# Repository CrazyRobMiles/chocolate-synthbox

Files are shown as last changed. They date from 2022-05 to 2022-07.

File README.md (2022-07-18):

# chocolate-synthbox
Raspberry Pi and PICO powered musical instrument running Pure Data

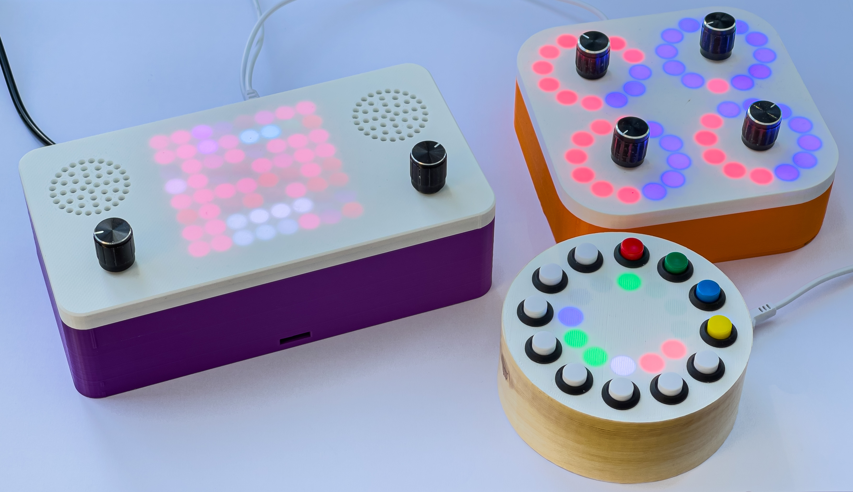
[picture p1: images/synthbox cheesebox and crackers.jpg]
Chocolate Synthbox, midi CheeseBox and crackers controller

# Video
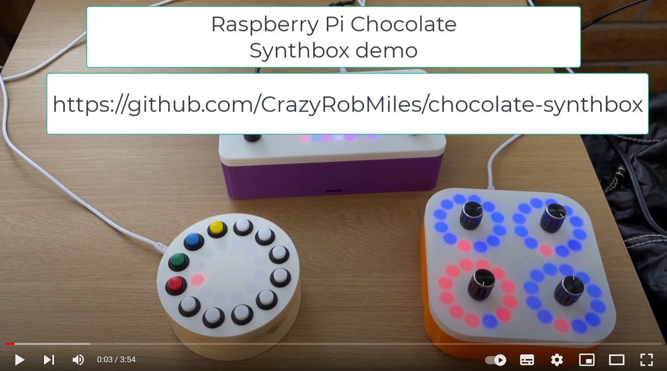
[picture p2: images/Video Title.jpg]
YouTube Screenshot (https://youtu.be/IFDrWa9PeCk)


To find out more about the device click on the image above to see a short video.
# Parts list
* Raspberry Pi. The software works with any Pi from the Zero upwards, but for more interesting sounds a Pi 4 is best
* Pi soundcard and amplifier. I used the Waveshare WM8960 but you can also use the Adafruit I2S 3W stereo speaker bonnet
* Pixel panel. The prototype uses an Adafruit NeoPixel NeoMatrix 8x8 - 64 RGB LED Pixel Matrix. This board is 71mm x 71mm. You can get WS2812 8x8 pixel matrices which are smaller (65mm square). There are printable case designs for each size. 
* Two rotary encoders (search for KY-040 encoder)
* A small speaker (You can get a very nice one from Pimoroni: https://shop.pimoroni.com/products/mini-speaker-4-3w)
* You can get the connectors you need to power the Pi and the PICO buy buying a USB-C Power Splitter for Raspberry Pi Touchscreen Display
* A Female 5.5mm x 2.1mm power socket 
* A power supply capable of supplying 5 volts at least 4 amps with a 5.5mm x 2.1mm plug.
* Connecting wire (search for "30 AWG wire wrap") which needs a wire wrap tool (search for "wire wrap tool").
* A box. There are a 3D printable designs available.
* Screws. You'll need some screws sized M2 4mm in length to fix things to the case (search for "laptop screws")
# Circuit Diagram
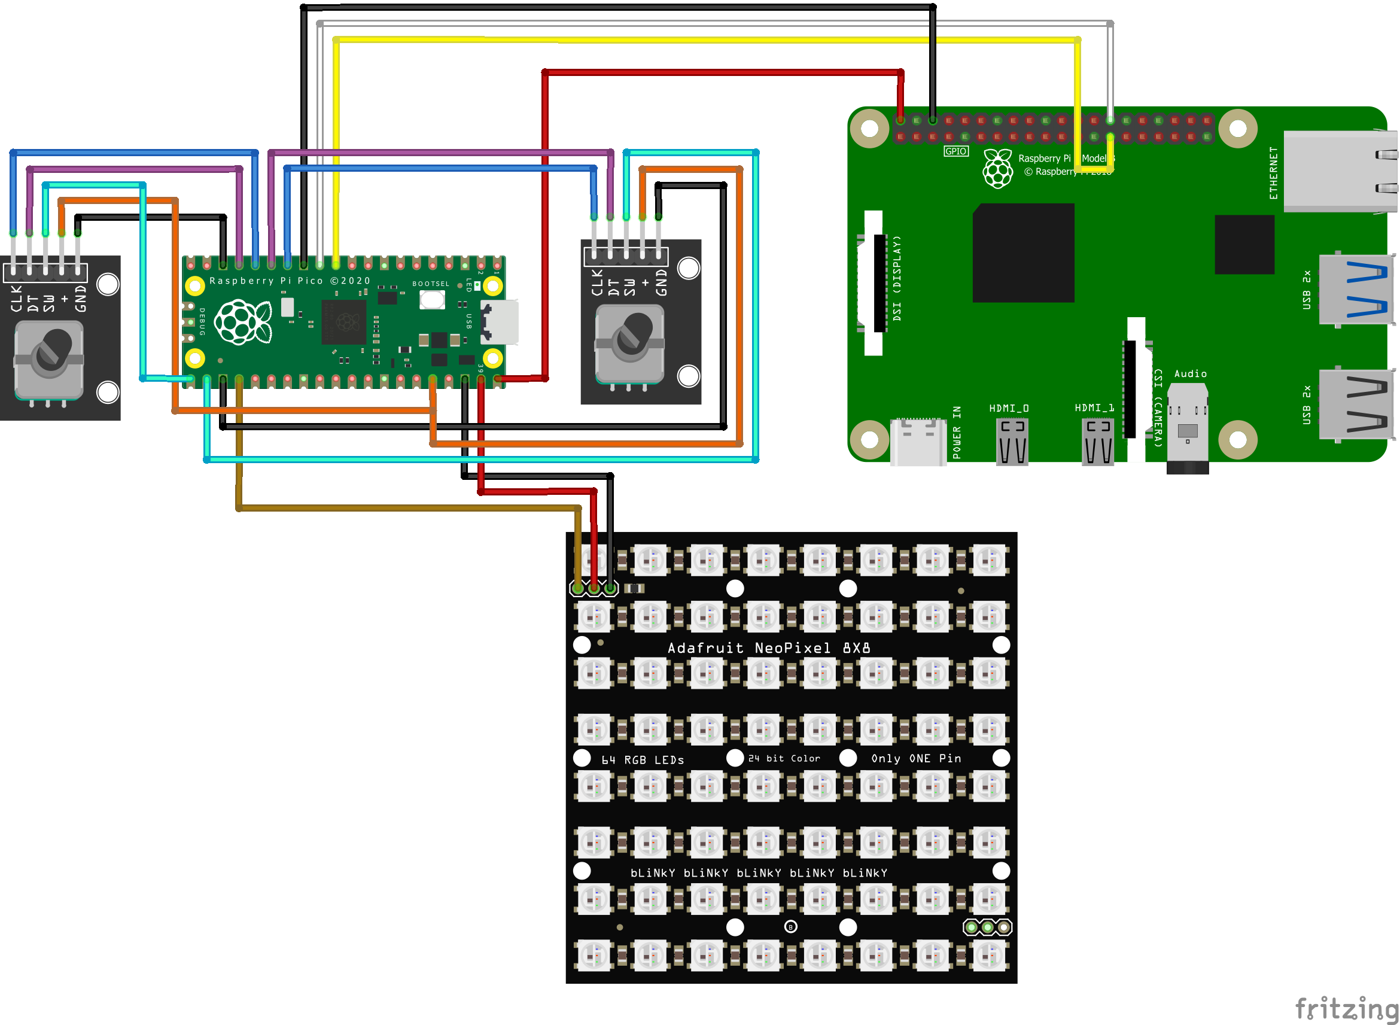
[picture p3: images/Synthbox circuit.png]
device circuit diagram

# Set up the Pico
Copy the program and libraries onto the Pico device. The Pico program is in the file code.py in the root of this repository. This is so you can use the Pymakr plugin to download and run the program from this repository. You will need to copy the contents of the lib folder onto your Pico as this contains Circuit Python libraries. 
# Set up the Raspberry Pi
## Get the operating system
Install the latest version of the Raspberry Pi operating system. Don't install the headless version because you will  need to use the desktop to configure Pure Data.
## Install the sound hardware 
Plug your sound hat onto your Raspberry Pi and install the driver software for it. If you are using the WaveShare sound hat you can use the installer [here](https://www.waveshare.com/wiki/WM8960_Audio_HAT#Install_Driver).

## Enable serial port 2
Note that serial port 2 in this configuration only works on a Raspberry Pi 4. 
Enable the serial port 2. This is the port that links the Pi to the Pico. We are going to use the second serial port which is exposed as /dev/ttyAMA1. It uses the GPIO0 (TX) and GPIO1 (RX) pins on the Raspberry Pi. These are on pins 27 and 28 respectively on the GPIO connector. We enable this port by adding the following line at the end of the file /boot/config.txt:
```
sudo nano /boot/config.txt
```
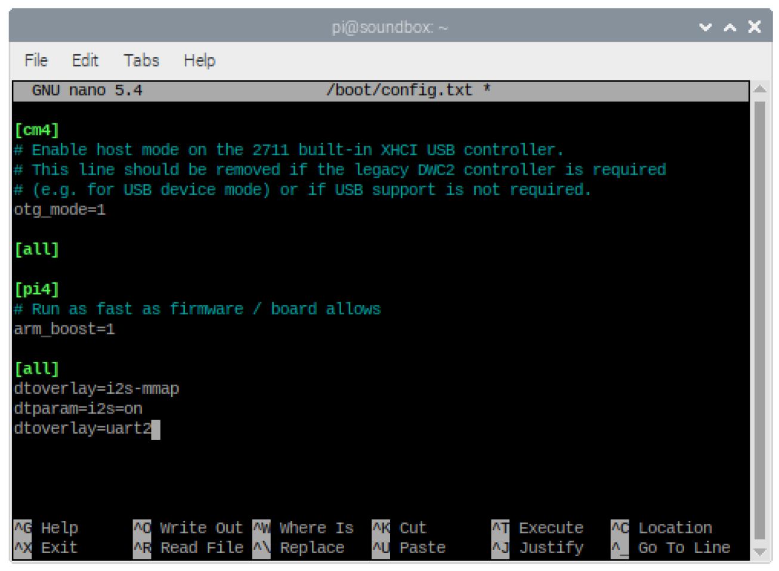
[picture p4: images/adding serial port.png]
nano editing config.txt


```
dtoverlay=uart2
```
Add the line as show above, write and save the file. If you want to use a different serial port you will have to modify the SerialComms.pd patch to change the name of the serial device it uses. 
## Install Pure Data and the Pure Data comport
Open up a terminal window and type:
```
sudo apt-get install puredata
sudo apt install pd-comport
```
This will install Pure Data and the comport object used by Pure Data patches to communicate over the serial port. 
## Copy the Pure Data patches to the Pi
You can use a usb drive or a remote desktop connection to copy these onto the your Pi. Copy the  Synthbox folder in the pd-code folder onto the desktop of your Pi. You must put the folder here, otherwise it won't be picked up automatically when the Pi starts. 
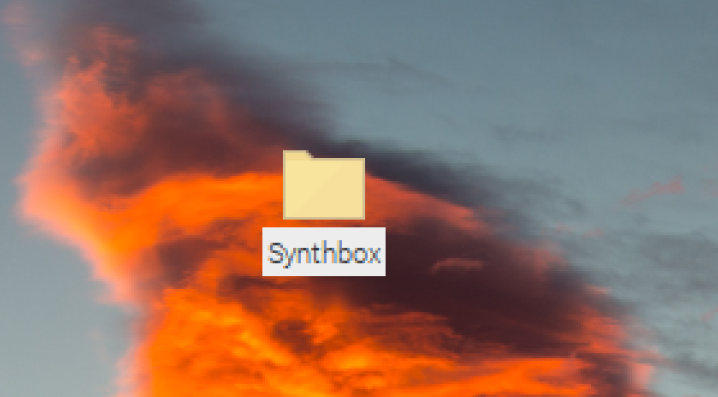
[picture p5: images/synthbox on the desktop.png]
Synthbox on the desktop

## Make Pure Data start on bootup
We can make Pure Data to start each time the Raspberry Pi boots by adding a line to the /etc/xdg/lxsession/LXDE-pi/autostart file. Open the file as follows:
```
sudo nano /etc/xdg/lxsession/LXDE-pi/autostart
```
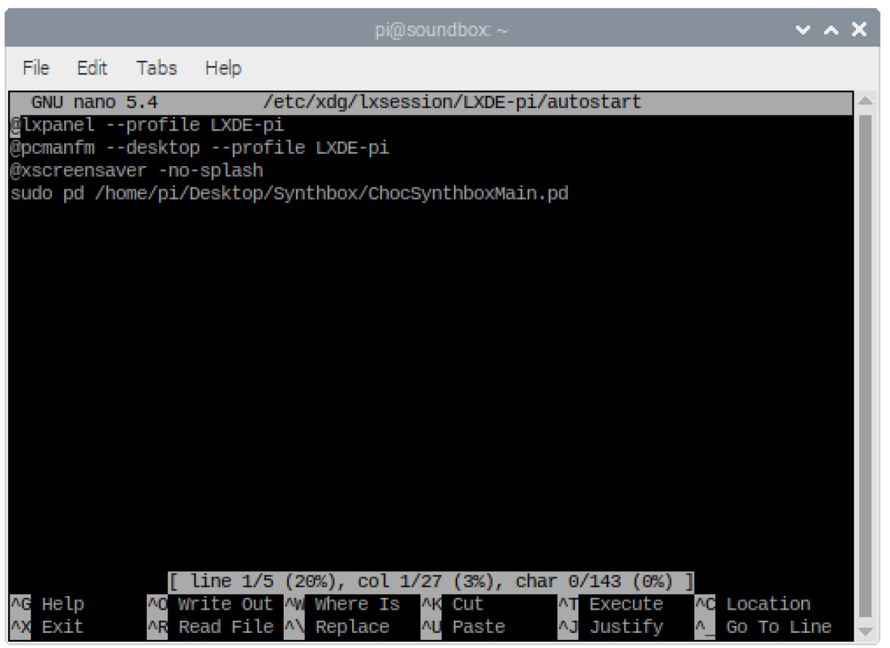
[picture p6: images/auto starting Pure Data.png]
nano editing autostart


Add the line:
```
sudo pd /home/pi/Desktop/Synthbox/ChocSynthboxMain.pd
```
Save the file and close it. Now each time your Pi starts it will run PureData.
## Connect Pure Data to the audio output
Next you need to tell Pure Data to use the audio output device we have installed.
Open up a desktop connection to the Pi, open Pure Data if it is not running and then select File>Preferences>Audio 
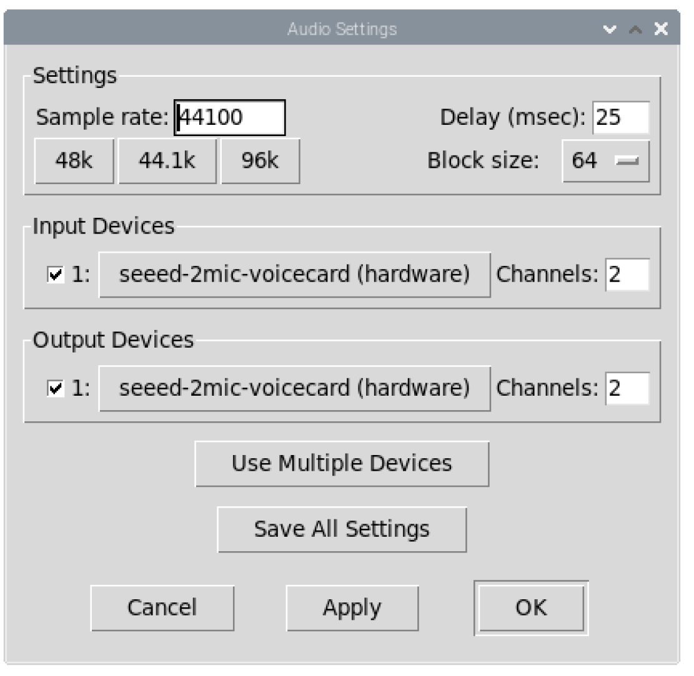
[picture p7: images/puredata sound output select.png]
Selecting Pure Data sound output

Click the input and output devices buttons and select the seeed devices as shown above. 
Then click Save All Settings and OK to save the settings and close the dialog.
## Connect Pure Data to your MIDI devices
Make sure that you have plugged your MIDI devices in before you start Pure Data running. It seems to only check for devices on startup. Open File>Preferences>Midi and select the option to use multiple devices. 
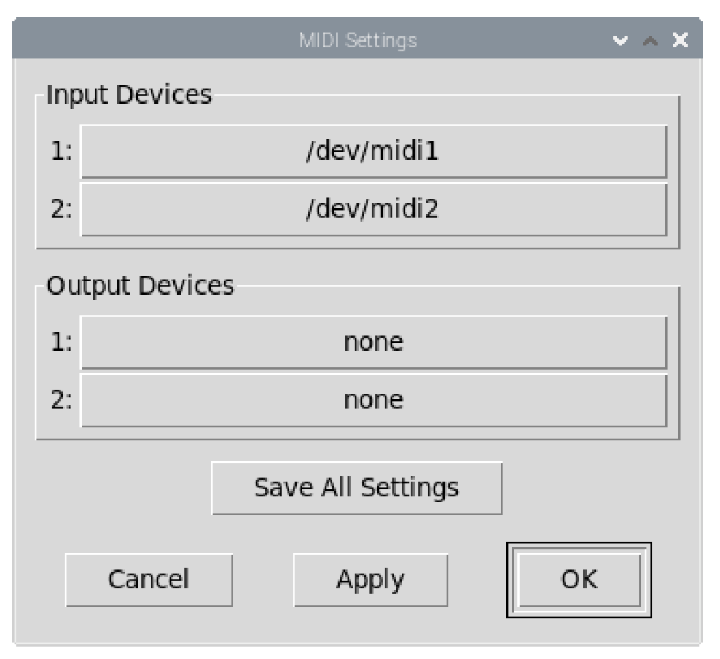
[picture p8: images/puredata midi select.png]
Selecting Pure Data sound output

Then select the MIDI input devices and click Save All Settings and then OK to close the dialog. 
## Run the patch
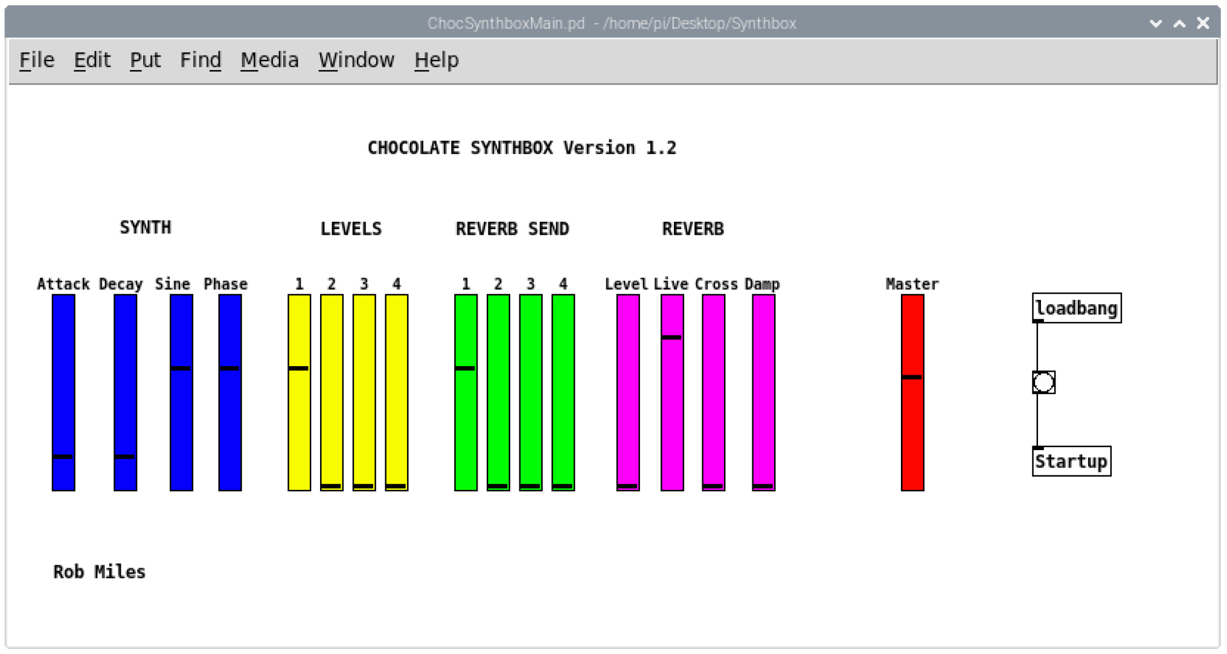
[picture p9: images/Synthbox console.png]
Pure Data console

When the patch is running the above is displayed on the Pi screen. You can use the sliders to adjust the values that are also controlled by the Pico Crackers controller. 

This is a work in progress. But it is fun to play with. 

I hope you have fun with it.

Rob Miles

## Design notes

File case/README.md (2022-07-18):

# Case

There are versions of the case for two sizes of led matrix. 

The case is created by a Python program that can be used to generate cases containing a large number of different elements. The program is called **BoxMacro.FCMacro** and runs inside the FreeCAD design tool which you can download from [here](https://www.freecadweb.org/downloads.php).

Each element in an enclosure is represented by one or more classes which are then automatically placed inside the base or the lid of the case. It is a bit of a pain to work with, I call it "3,000 lines of technical debt" but it does the job.

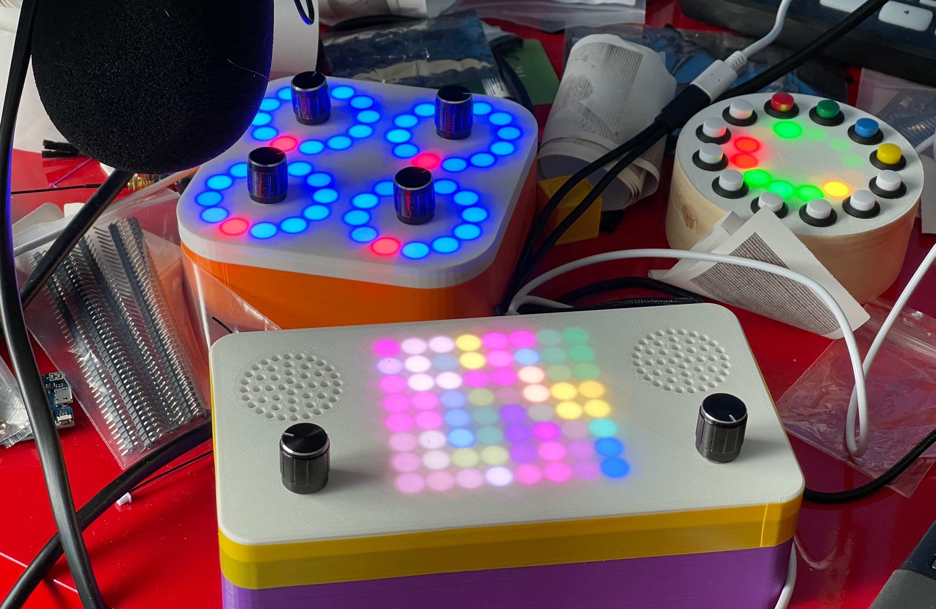
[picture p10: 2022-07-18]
images/soundbox controller and cheesebox.jpg

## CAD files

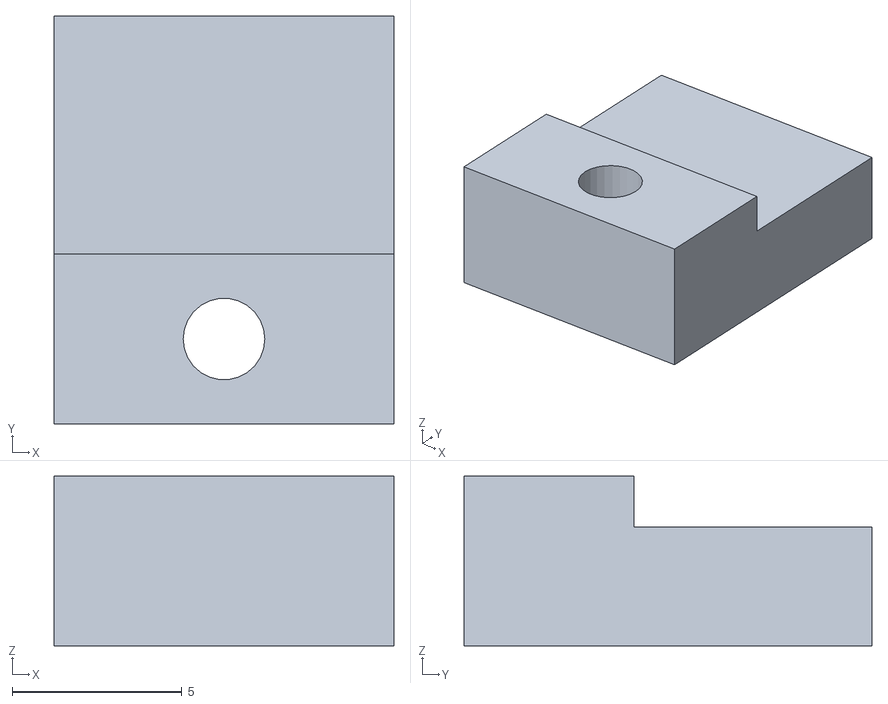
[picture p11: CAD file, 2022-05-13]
case/led panel clamps/clamp.stl
10.0 x 12.0 x 5.00

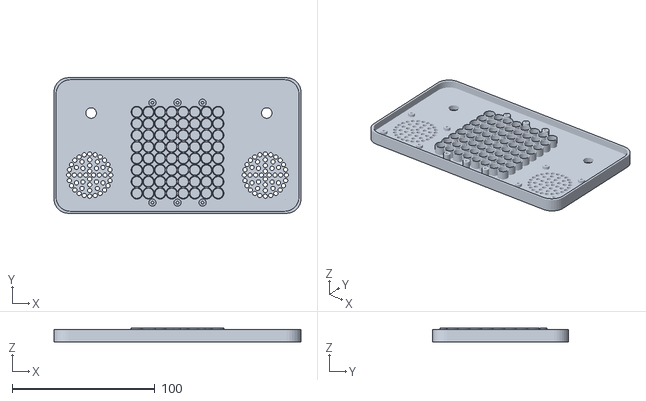
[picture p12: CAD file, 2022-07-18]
case/Synthbox 65mm matrix/top.stl
173.0 x 95.0 x 10.0

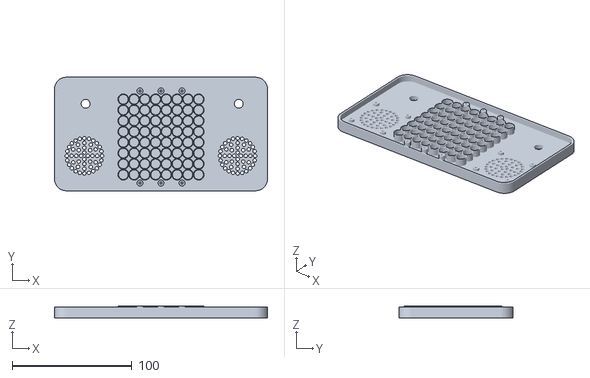
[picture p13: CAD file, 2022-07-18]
case/Synthbox 71mm matrix/top.stl
178.0 x 95.0 x 10.0

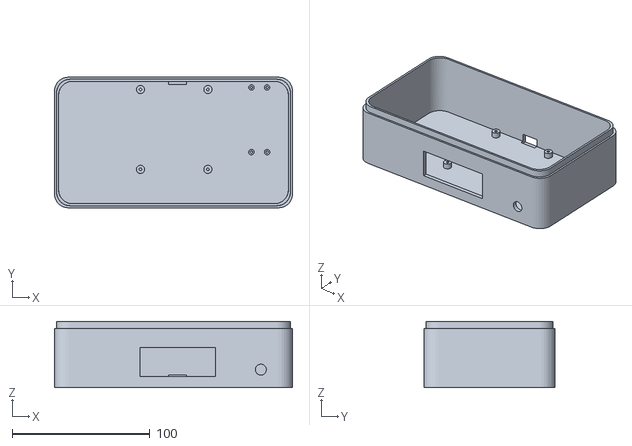
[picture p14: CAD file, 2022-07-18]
case/Synthbox 65mm matrix/bottom.stl
173.0 x 95.0 x 48.0

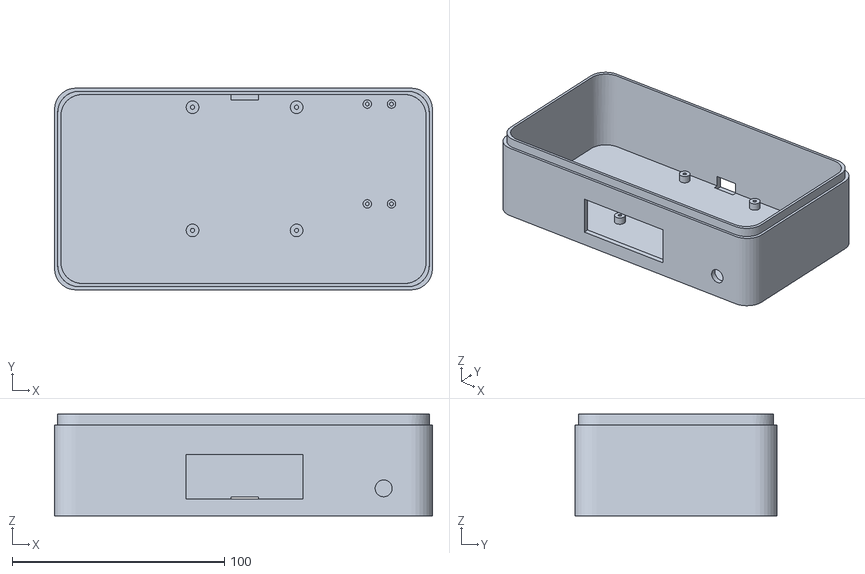
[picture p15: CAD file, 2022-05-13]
case/Synthbox 71mm matrix/bottom.stl
178.0 x 95.0 x 48.0

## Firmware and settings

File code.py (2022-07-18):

import board
import time
import busio
import gc
import board
import neopixel
import rotaryio
from digitalio import DigitalInOut, Direction, Pull
from adafruit_debouncer import Debouncer

class Types:
    NUMBER_INPUT = "no"
    TEXT_INPUT = "text"

class Col:
    
    RED = (255, 0, 0)
    YELLOW = (255, 150, 0)
    GREEN = (0, 255, 0)
    CYAN = (0, 255, 255)
    BLUE = (0, 0, 255)
    MAGENTA = (255, 0, 255)
    WHITE = (255, 255, 255)
    BLACK = (0, 0, 0)
    GREY = (10, 10, 10)
    VIOLET = (127,0,155)
    INDIGO = (75,0,130)
    ORANGE = (255,165,0)
       
    values=(RED, GREEN, BLUE, YELLOW, MAGENTA, CYAN, GREY, WHITE)
     
   
    @staticmethod
    def dim(col):
        return (col[0]/40, col[1]/40, col[2]/40)

class ControllerConfig():
    
    def __init__(self, name, min_val=0, max_val=127,turns=1.0,init_value=0,
                 controller_value = 0, background_col = Col.BLUE,
                 val_col = Col.RED):
        self.name = name
        self.min_val = min_val
        self.max_val = max_val
        self.turns = turns
        self.encoder_value = 0
        self.init_value = init_value
        self.controller_value = init_value
        self.val_col = val_col
        self.background_col = background_col
 
class SerialControllerConfig(ControllerConfig):
    
    def __init__(self, name, min_val=0, max_val=127,turns=1.5,init_value=0,
                 controller_value = 0, background_col = Col.BLUE,
                 val_col = Col.RED, serial_port = None, serial_channel=1,pixel_start=0,no_of_pixels=8, stride=-8):
        super(SerialControllerConfig,self).__init__(
            name, min_val, max_val,turns,init_value,
                 controller_value, background_col,
                 val_col)
        self.serial_port = serial_port
        self.serial_channel = serial_channel
        self.pixel_start = pixel_start
        self.no_of_pixels = no_of_pixels
        self.stride = stride

class Controller():
    def __init__(self, client, name, encoder_pin1, encoder_pin2, pulses_rev,
                 button_pin, forward, configs, cursor_col = Col.WHITE
                 ):
        self.name = name
        self.client =  client
        self.screen_manager = client.screen_manager
        self.encoder= rotaryio.IncrementalEncoder(encoder_pin1, encoder_pin2)
        self.pulses_rev = pulses_rev
        self.last_encoder_position = 0
        tmp_pin = DigitalInOut(button_pin)
        tmp_pin.pull = Pull.UP
        self.button_debounce = Debouncer(tmp_pin,interval=0.01)
        self.activate_display()
        self.forward = forward
        self.first_run = True
        self.cursor_col = cursor_col
        self.configs = configs
        self.active_config_no = 0
        self.active_config = configs[0]
    
    def activate_display(self):
        self.encoder_display_time_end = time.monotonic() + 2

    def display_active(self):
        if time.monotonic() < self.encoder_display_time_end :
            return True
        else:
            return False

    def set_range(self,min_val,max_val,turns,pulses_rev):
        self.min = min_val
        self.max = max_val
        self.turns = turns
        
    def set_pixel_col(self,pixel_number,new_col):
        if self.screen_manager.pixels[pixel_number] != new_col:
            self.screen_manager.pixels[pixel_number] = new_col
            self.screen_manager.controls_active = True
        
    def draw_cursor(self):
        for config in self.configs:
            pixels = config.no_of_pixels
            stride = config.stride
            pulse_limit = int(self.pulses_rev * config.turns)-1
            turn_amount = config.encoder_value / pulse_limit
            cursor = int((pixels-1)*turn_amount)
            pos=0
            pix = config.pixel_start
            while pos < pixels:
                if pos<=cursor:
                    if pos == cursor:
                        if config == self.active_config:
                            self.set_pixel_col(pix, self.cursor_col)
                        else:
                            self.set_pixel_col(pix, config.val_col)
                    else:
                        self.set_pixel_col(pix, config.val_col)
                else:
                    self.set_pixel_col(pix, config.background_col)
                pos = pos + 1
                pix = pix + stride
            
    def update_encoder(self):
        new_encoder_position = self.encoder.position
        encoder_change = self.last_encoder_position - new_encoder_position
        
        if encoder_change != 0 or self.first_run:
            self.activate_display()
            if self.forward:
                new_pos = self.active_config.encoder_value - encoder_change
            else:
                new_pos = self.active_config.encoder_value + encoder_change
                
            if new_pos<0:
                new_pos=0
                
            pulse_limit = int(self.pulses_rev * self.active_config.turns)-1
            
            if new_pos>=pulse_limit:
                new_pos=pulse_limit
                 
            if self.active_config.encoder_value != new_pos or self.first_run:
                self.first_run = False
                self.active_config.encoder_value = new_pos
                turn_amount = new_pos / pulse_limit
                val_range = self.active_config.max_val - self.active_config.min_val
                scaled_change = turn_amount * val_range
                self.active_config.controller_value=scaled_change
                self.encoder_changed()
       
        self.last_encoder_position = new_encoder_position
        
    def update(self):
        self.button_debounce.update()
        if self.button_debounce.fell:
            self.activate_display()
            self.button_down()
        if self.button_debounce.rose:
            self.button_up()
        self.update_encoder()

    def draw(self):
        if self.display_active():
            self.draw_cursor()
            return True
        else:
            return False

    def reset(self):
        self.count=0
        
    def step_controller(self):
        self.active_config_no = (self.active_config_no + 1) % len(self.configs)
        self.active_config = self.configs[self.active_config_no]
        self.draw_cursor()
    
    def button_down(self):
        self.step_controller()
        
    def button_up(self):
        pass


class SerialController(Controller):
    
    def __init__(self, client, name, encoder_pin1, encoder_pin2, pulses_rev,
                 button_pin, forward, configs):
        super(SerialController,self).__init__(client = client, name = name,
                 encoder_pin1 = encoder_pin1, encoder_pin2 = encoder_pin2,
                 pulses_rev = pulses_rev, button_pin = button_pin,
                 forward = forward,
                 configs=configs)
    
    def encoder_changed(self):
        print("Controller changed: ",self.active_config.controller_value,self.active_config.serial_channel)
        if self.client.serial_port != None:
            b1 = int(self.active_config.serial_channel)
            b2 = int(self.active_config.controller_value)
            message = "encoder " + str(b1) + " " + str(b2) + "\n"
            send_buffer = bytes(message,"ascii")
            print("Sending to serial:", send_buffer)
            self.client.serial_port.write(send_buffer)


class PixelManager():
    def __init__(self, pixels, pixel_no):
        self.pixel_no = pixel_no
        self.col = [0,0,0]
        self.deltas = [0,0,0]
        self.current_step=0
        self.no_of_steps=0
    
    def set_col(self,new_col):
        for i in range(0,3):
            self.col[i]=new_col[i]

    def update(self):
        if self.current_step < self.no_of_steps:
            for i in range(0,3):
                c = self.col[i] + self.deltas[i]
                if c<0:
                    c=0
                if c>255:
                    c=255
                self.col[i]=c
            self.current_step = self.current_step + 1

    def draw(self, pixels):
        pixels[self.pixel_no] = self.col

    def start_fade(self,target_col,no_of_steps):
        self.current_step = 0
        self.no_of_steps = no_of_steps
        if no_of_steps == 0:
            self.set_col(target_col)
        else:
            for i in range(0,3):
                self.deltas[i] = (target_col[i] - self.col[i]) / no_of_steps

class ScreenManager():

    font_5x3 = (
        (0, 0),         # 32 - 'Space'
        (23,),          # 33 - '!'
        (3, 0, 3),      # 34 - '"'
        (31, 10, 31),   # 35 - '#'
        (22, 31, 13),   # 36 - '$'
        (9, 4, 18),     # 37 - '%'
        (10, 21, 26),   # 38 - '&'
        (3,),           # 39
        (14, 17),       # 40 - '('
        (17, 14),       # 41 - ')'
        (10, 4, 10),    # 42 - '*'
        (4, 14, 4),     # 43 - '+'
        (16, 8),        # 44 - ','
        (4, 4, 4),      # 45 - '-'
        (16,),          # 46 - '.'
        (8, 4, 2),      # 47 - '/'
        (31, 17, 31),   # 48 - '0'
        (0, 31),        # 49 - '1'
        (29, 21, 23),   # 50 - '2'
        (17, 21, 31),   # 51 - '3'
        (7, 4, 31),     # 52 - '4'
        (23, 21, 29),   # 53 - '5'
        (31, 21, 29),   # 54 - '6'
        (1, 1, 31),     # 55 - '7'
        (31, 21, 31),   # 56 - '8'
        (23, 21, 31),   # 57 - '9'
        (10,),          # 58 - ':'
        (16, 10),       # 59 - ';'
        (4, 10, 17),    # 60 - '<'
        (10, 10, 10),   # 61 - '='
        (17, 10, 4),    # 62 - '>'
        (1, 21, 3),     # 63 - '?'
        (14, 21, 22),   # 64 - '@'
        (30, 5, 30),    # 65 - 'A'
        (31, 21, 10),   # 66 - 'B'
        (14, 17, 17),   # 67 - 'C'
        (31, 17, 14),   # 68 - 'D'
        (31, 21, 17),   # 69 - 'E'
        (31, 5, 1),     # 70 - 'F'
        (14, 17, 29),   # 71 - 'G'
        (31, 4, 31),    # 72 - 'H'
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
        (31, 31, 31) # 127 - 'Full Block'
    )

    def __init__(self, controller, gpio, width,height):
        self.controller = controller
        self.panel_width = width
        self.panel_height = height
        self.no_of_pixels = width*height
        self.pixels = neopixel.NeoPixel(gpio,self.no_of_pixels,auto_write=False)
        self.pixel_managers = []
        for i in range(0,self.no_of_pixels):
            self.pixel_managers.append(PixelManager(self.pixels,i))
        self.pixels.brightness = 0.3
        self.update_interval = 0.02
        self.draw_interval = 0.02
        self.controls_active = True
        self.next_update_time = time.monotonic() + self.update_interval
        self.next_draw_time = time.monotonic() + self.draw_interval
        self.control_display_end_time = time.monotonic() + 2
        self.start_text_display()

    # draw the text on the display taking into account scrolling

    def get_char_design(self,ch):
        ch_offset = ord(ch) - ord(' ')
        if ch_offset<0 or ch_offset>len(self.font_5x3):
            return None
        return self.font_5x3[ch_offset]
    
    def draw_text(self):

        if self.text == '':
            return

        x = self.text_x
        y = self.text_y

        ch_pos = self.text_char_pos
        column = self.text_char_column
        pixel_offset = x + (y*self.panel_width)

        while ch_pos < len(self.text):

            if pixel_offset >= self.no_of_pixels:
                return

            ch = self.text[ch_pos]

            char_design = self.get_char_design(ch)

            if char_design == None:
                return

            char_design_length = len(char_design)
            
            while column < char_design_length:
                if x >= self.panel_width:
                    return
                # display the character raster
                font_column =char_design[column]
                bit = 1
                draw_pixel = pixel_offset

                while(bit<32):
                    if draw_pixel >= self.no_of_pixels:
                        return

                    if font_column & bit:
                        self.pixels[draw_pixel] = self.text_colour

                    # move on to the next bit in the column
                    bit = bit + bit
                    # move onto the next pixel to draw
                    draw_pixel = draw_pixel + self.panel_width

                column = column + 1
                pixel_offset = pixel_offset + 1 
                x = x + 1

            # reached the end of displaying a character - move to the next one
            x = x + 1
            ch_pos = ch_pos + 1
            pixel_offset = pixel_offset + 1 
            column = 0

    def start_scroll(self):

        if len(self.text) == 0:
            return

        self.text_char_column = 0
        self.text_step=0

        ch = self.text[self.text_char_pos]

        self.text_char_design = self.get_char_design(ch)

    def scroll_text(self):

        if len(self.text) == 0:
            return

        self.text_char_column = self.text_char_column + 1

        if self.text_char_column >= len(self.text_char_design):
            self.text_char_pos = self.text_char_pos + 1
            if self.text_char_pos >= len(self.text):
                self.text_char_pos = 0
                if self.scroll_count >0:
                    self.scroll_count = self.scroll_count-1
                    if self.scroll_count <=0:
                        self.text='' 
                        return
            self.start_scroll()

    def update_text(self):

        if len(self.text) == 0:
            return

        self.text_step = self.text_step + 1

        if self.text_step >= self.text_step_limit:
            self.scroll_text()
            self.text_step = 0

    def start_text_display(self,text='',colour=Col.BLACK,steps=8000,x=0,y=0,scroll_count=1):

        # put some spaces on the front so the text scrolls in from the right
        self.text = '     ' + text
        self.text_colour = colour
        self.text_step_limit = steps
        self.text_x = x
        self.text_y = y

        self.text_step = 0
            
        self.scroll_count = scroll_count

        if len(self.text) == 0:
            return

        self.text_char_pos = 0

        self.start_scroll()

    def update(self, current_time ):
        if current_time >= self.next_update_time:
            self.next_update_time = current_time + self.update_interval

            for pixel in self.pixel_managers:
                pixel.update()

            self.update_text()

    # returns True if the display is dirty and must be updated
    def draw(self,current_time):

        if current_time < self.next_draw_time :
            return False
        else:
            self.next_draw_time = current_time + self.draw_interval
            for pixel in self.pixel_managers:
                pixel.draw(self.pixels)
            self.draw_text()
            return True

class ScreenCommand():

    def get_pixel_offset(self,x,y):
        return y*self.width + x

    def __init__(self, controller):
        self.controller = controller
        self.mgr = controller.screen_manager
        self.width = controller.screen_manager.panel_width
        self.height = controller.screen_manager.panel_height
 
    def process_command(self):
        result = []
        con = self.controller

        for default_item in self.defaults:
            if (con.packet_buffer_read==con.packet_buffer_pos) or (con.packet_input_buffer[con.packet_buffer_read] == ';'):
                # end of the buffer - add the default
                result.append(default_item[1])
            else:
                # read an item
                command_item = con.get_next_packet_item()
                if command_item == None:
                    result.append(default_item[1])
                else:
                    # make sure it is the right type
                    if command_item[0] != default_item[0]:
                        result.append(default_item[1])
                    result.append(command_item[1])
        return result


# Draw blocks all in the same colour
class C_0_DrawBlock(ScreenCommand):

    def __init__(self,controller):
        super(C_0_DrawBlock,self).__init__(controller)

        self.defaults = ( 
            (Types.NUMBER_INPUT,0),           # 0 red
            (Types.NUMBER_INPUT,0),           # 1 green
            (Types.NUMBER_INPUT,0),           # 2 blue
            (Types.NUMBER_INPUT,5),           # 3 steps
            (Types.NUMBER_INPUT,0),           # 4 x
            (Types.NUMBER_INPUT,0),           # 5 y
            (Types.NUMBER_INPUT,self.width),  # 6 width
            (Types.NUMBER_INPUT,self.height)  # 7 height
        )
            
        self.current_step=0
        self.no_of_steps=0

    def process_command(self):

        com = super(C_0_DrawBlock,self).process_command()

        if com == None:
            return

        target = (com[0],com[1],com[2])

        steps = com[3]
        x = com[4]
        y = com[5]
        w = com[6]
        h = com[7]
        for yp in range(0,h):
            fy = y + yp
            if fy < self.height:
                for xp in range (0,w):
                    fx = x + xp
                    if fx < self.width:
                        pix_no = self.get_pixel_offset(fx,fy)
                        self.mgr.pixel_managers[pix_no].start_fade(target,steps) 

# Draw dots at positions on the screen all of the same colour
class C_1_Drawdot(ScreenCommand):

    def __init__(self,controller):
        super(C_1_Drawdot,self).__init__(controller)
        self.defaults = ( 
            (Types.NUMBER_INPUT,0),           # 0 red
            (Types.NUMBER_INPUT,0),           # 1 green
            (Types.NUMBER_INPUT,0),           # 2 blue
            (Types.NUMBER_INPUT,5),           # 3 steps
            (Types.NUMBER_INPUT,0),           # 4 x
            (Types.NUMBER_INPUT,0)            # 5 y
        )
            
        self.current_step=0
        self.no_of_steps=0

    def process_command(self):
        com = super(C_1_Drawdot,self).process_command()

        if com == None:
            return

        target = (com[0],com[1],com[2])

        steps = com[3]
        x = com[4]
        y = com[5]
        pix_no = self.get_pixel_offset(x,y)
        if pix_no < len(self.mgr.pixel_managers):
            self.mgr.pixel_managers[pix_no].start_fade(target,steps)

class C_2_DrawText(ScreenCommand):
    def __init__(self,controller):
        super(C_2_DrawText,self).__init__(controller)
        self.defaults = ( 
            (Types.NUMBER_INPUT,0),           # 0 red
            (Types.NUMBER_INPUT,0),           # 1 green
            (Types.NUMBER_INPUT,0),           # 2 blue
            (Types.NUMBER_INPUT,5),           # 3 steps
            (Types.NUMBER_INPUT,0),           # 4 x
            (Types.NUMBER_INPUT,0),           # 5 y
            (Types.TEXT_INPUT,"hello world"), # 6 text
            (Types.NUMBER_INPUT,0)            # 7 repeat scroll
        )
            
        self.current_step=0
        self.no_of_steps=0

    def process_command(self):
        com = super(C_2_DrawText,self).process_command()

        if com == None:
            return

        colour = (com[0],com[1],com[2])

        steps = com[ 3]
        x = com[4]
        y = com[5]
        text = com[6]
        scroll = com[7]

        self.mgr.start_text_display(text,colour,steps,x,y,scroll)

class C_3_SetCtrl(ScreenCommand):
    def __init__(self,controller):
        super(C_3_SetCtrl,self).__init__(controller)
        self.defaults = ( 
            (Types.NUMBER_INPUT,0),           # 0 ctrl
            (Types.NUMBER_INPUT,0),           # 1 value
        )

    def process_command(self):
        com = super(C_3_SetCtrl,self).process_command()

        if com == None:
            return

        ctrl_no = com[0]
        value = com[1]
        print("CtrlL",ctrl_no,"Value:",value)
        
        result = controller.find_serial_controller_by_number(ctrl_no)

        if result==None:
            return
        
        (serial_controller,config) = result

        print("Controller: ",config.name)
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

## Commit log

2022-05-13 just about to rewrite the renderer....
    [bottom.stl, clamp.stl, lightpad.FCStd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]
2022-07-18 First complete release
    [bottom.stl, clamp.stl, lightpad.FCStd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]
